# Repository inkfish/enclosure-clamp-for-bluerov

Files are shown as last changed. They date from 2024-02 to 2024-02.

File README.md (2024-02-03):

# Parametric Model of Blue Robotics Enclosure Clamp

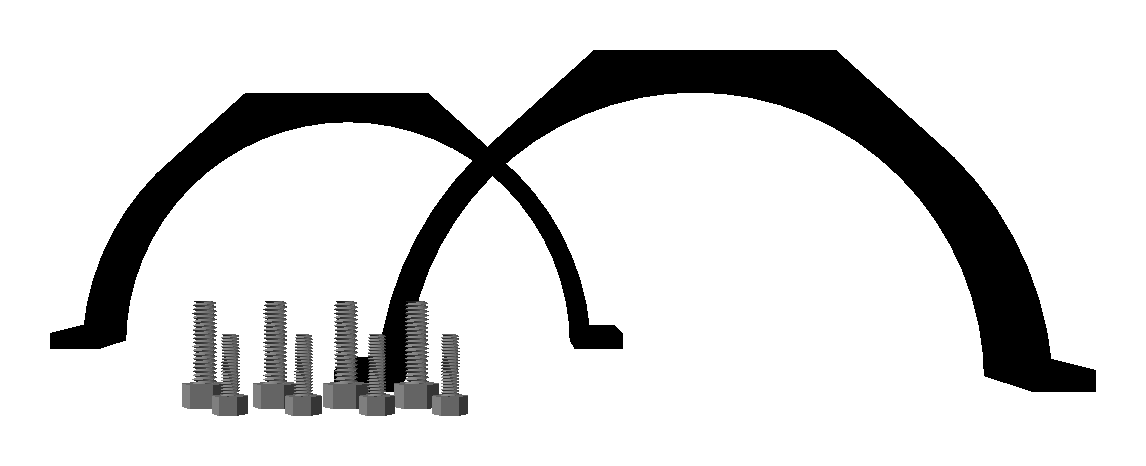
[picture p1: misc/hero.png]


This repository contains a parametric OpenSCAD model for the [Blue Robotics Enclosure Clamp][store] used with their line of Watertight Enclosures.

This model is based on the CAD models released by Blue Robotics and available on the [product page][store] and as a [3D printable model][printable], licensed [CC BY 4.0][license].

## Usage

Clone this repository with submodules:

    git submodule init --update

Use OpenSCAD to render one of the files `enclosure-clamp-{...}.scad`. Export the rendering as an STL file and 3D print.

## Variant Notes

### 2" (50mm) series

The official 2" series clamp is of slightly different design than the 3" and 4" series, featuring a wider 4.5mm diameter hole on one flange, and more fillets. These features are not reproduced on this model.

  * 4 x M4x10 socket head cap screws, for flanges and base
  * 2 x adhesive rubber strip (details TBD)

### 3" (75mm) and 4" (100mm) series

  * 4 x M3x12 socket head cap screws, for flanges
  * 4 x M4x14 socket head cap screws, for base
  * 2 x adhesive rubber strips (acrylic tube: 1/16", aluminum: 1/8")

### 6" and 8" series

There is no first-party enclosure clamp for the 6" and 8" enclosure series. The design file for the 6" series uses dimensions derived from the 4" series. This is a good starting point for other enclosure diameters.

Mounting hardware is the same as for the 3" and 4" series.

[license]: https://creativecommons.org/licenses/by/4.0/
[printable]: https://www.printables.com/model/397769-watertight-enclosure-clamps
[store]: https://bluerobotics.com/store/watertight-enclosures/enclosure-clamp/

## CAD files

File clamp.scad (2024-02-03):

// Flange Clamp for the Blue Robotics Watertight Enclosure
//
// This document is a parametric design that does not include dimensions.
// Please use one of the accompanying files, e.g., enclosure-clamp-3in.scad.
//
// Based on the WTE3-M-CLAMP-R1 model by Blue Robotics:
// https://bluerobotics.com/store/watertight-enclosures/enclosure-clamp/
//
// OpenSCAD model by Ryan Govostes.
// License: CC BY 4.0 (https://creativecommons.org/licenses/by/4.0/)


fillet_radius = 1.00;


$fn = 64;


translate([0, 0, -(height/2)])
linear_extrude(height) {
    difference() {
        union() {
            hull() {
                translate([0, circle_y_offset])
                circle(r=(radius + thickness));

                translate([-(base_width/2), -depth])
                square(size=[base_width, 1]);
            }

            translate([-(width/2), -thickness])
            square([width, thickness]);
        }

        translate([0, circle_y_offset])
        circle(r=radius);

        // Cut off the top half of the shape
        translate([-200, 0])
        square([400, 400]);
    }
}

// TODO: Flange fillets
// TODO: Mounting and flange holes

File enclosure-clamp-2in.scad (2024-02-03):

// Flange Clamp for the Blue Robotics Watertight Enclosure, 2" (50mm) series
//
// Based on the WTE2_CLAMP_BR-102474_PUBLIC model by Blue Robotics:
// https://bluerobotics.com/store/watertight-enclosures/enclosure-clamp/
//
// OpenSCAD model by Ryan Govostes.
// License: CC BY 4.0 (https://creativecommons.org/licenses/by/4.0/)

// Note: The 2" series clamp is of slightly different design than the 3" and 4"
// series, featuring a wider 4.5mm diameter hole on one flange, and more
// fillets. These features are not reproduced on this model.


radius = 31.04;  // Tube OD - aluminum: 58.0 +/- 0.2mm, acrylic: 58.0 +/- 0.5mm
thickness = 3.00;

width = 86.40;
depth = 36.00;
height = 16.70;

base_width = 26.10;
base_hole_diameter = 3.30;  // M4x10
base_hole_depth = 4.50;

flange_hole_diameter = 3.30;  // M4x10


// The circle is centered 0.50 mm above the X axis. This detail is not
// captured in the mechanical drawing but has been confirmed by Blue Robotics:
//
// https://discuss.bluerobotics.com/t/small-offset-in-mounting-clamp/15944/2
circle_y_offset = 0.50;


include <clamp.scad>;

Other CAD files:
enclosure-clamp-3in.scad
enclosure-clamp-4in.scad
enclosure-clamp-6in.scad
misc/extrusion-test.scad
misc/hero.scad

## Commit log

2024-02-03 Move circle_y_offset definition to parameter files
    [clamp.scad, enclosure-clamp-2in.scad, enclosure-clamp-3in.scad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]
2024-02-03 Add 6" series clamp derived from the 4" series
    [enclosure-clamp-6in.scad]
2024-02-03 Add rcolyer/threads-scad library
2024-02-03 Add hero image to README
    [hero.scad]
